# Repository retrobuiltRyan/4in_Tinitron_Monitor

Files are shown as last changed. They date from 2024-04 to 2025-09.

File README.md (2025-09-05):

# 4in_Tinitron_Monitor
4in 800x480 LCD Monitor that looks like a Sony Trinitron Wega.<br>
There are two different "TV" assemblies in this repo. <br>
a) TV shaped enclosure for a 4inch LCD <br>
b) TV shaped enclosure for a 4inch LCD + Raspberry Pi 3<br>
frame for commerical

https://www.youtube.com/watch?v=1_5VtVP_qF4
P1090145

mechanical overview

SIGNIFICANTLY IMPORTANT: This screen has a native portrait layout. Your HDMI source must support rotation. Otherwise this device will be useless.
If using a Pi, these settings [highlighted] will work.
Raspberry Pi 480x800 config settings

Parts and Links:
P1090100

### Parts List

| Item | Description | Qty | Cost | Line Total | Vendor | Link |
|---|---|-----|---|---|---|---|
| 1 | 4 Inch HD HDMI USB LCD Touch Screen 4" Display Module 800×480 TFT | 1 | $22.78 | $22.78 | AliExpress | [Link](https://www.aliexpress.us/item/3256803352252987.html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) |
| 2 | HDMI M-to-F 90 degree Ribbon Extension | 1 | $5.41  | $5.41 | AliExpress | [Link](https://www.aliexpress.us/item/3256802099720174.html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) |
| 3 | USB-C Panel Mount Breakout | 1 | $0.50  | $0.50 | AliExpress | [Link](https://www.aliexpress.us/item/3256805810676482.html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) |
| 4 | 3D printed Case (84 grams) | 1 | $1.25  | $1.25 | n/a | |
| 5 | Push Button latching 12mm dia (on/off switch) | 1 | $0.75  | $0.75 | ebay? | |
| 6 | M3 Threaded Inserts | 8 | $0.15  | $1.20 | amazon? | |
| 7 | M3x16mm button head hex screw | 2 | $0.05  | $0.10 | amazon? | |
| 8 | M3x6mm button head hex screw | 6 | $0.05  | $0.30 | amazon? | |
| 9 | M2 x 8mm head hex screw | 5 | $0.05  | $0.25 | amazon? | |
| 10 | M2 nuts | 2 | $0.02  | $0.04 | amazon? | |

**Total: $32.58**

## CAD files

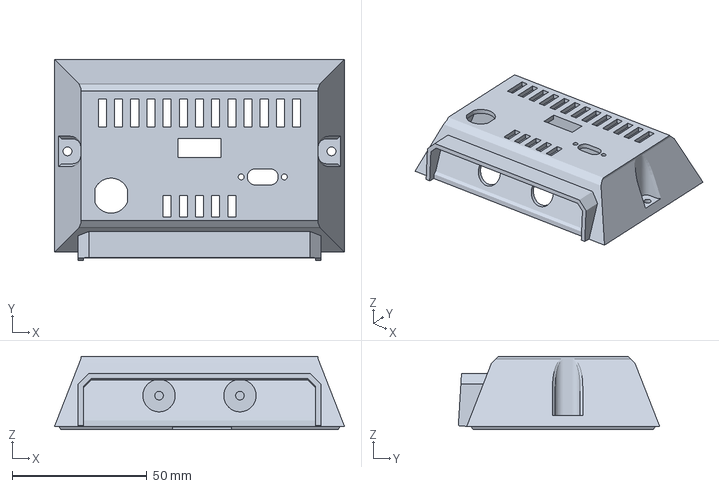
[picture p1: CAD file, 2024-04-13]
Tinitron Shell Body full base 1.1.3MF
107.5 x 74.7 x 27.2 mm

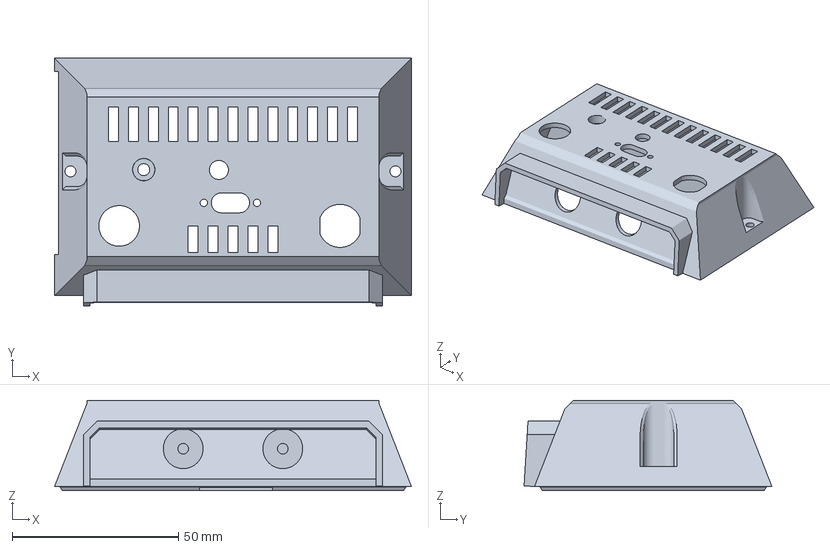
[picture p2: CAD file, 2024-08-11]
Tinitron Shell Rear+pi3.3MF
107.5 x 74.7 x 27.2 mm

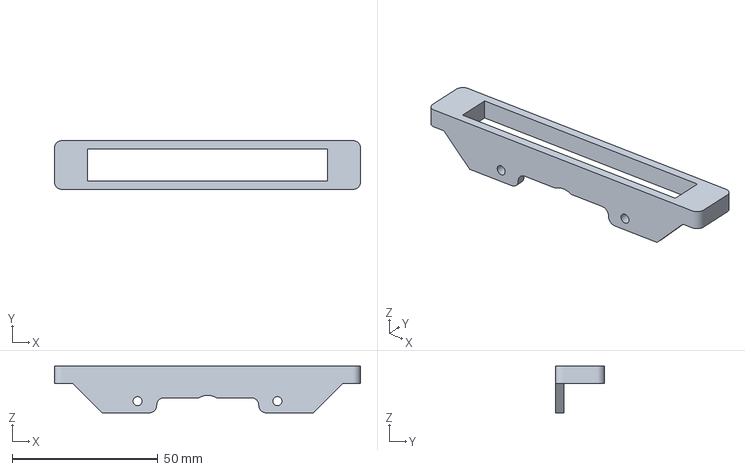
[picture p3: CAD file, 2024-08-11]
Volume LED Mount Bracket.3MF
105.0 x 16.8 x 16.0 mm

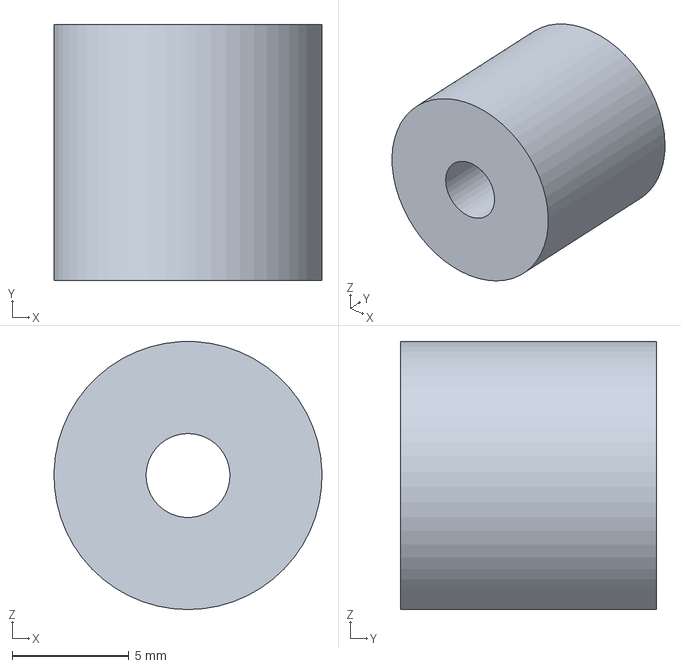
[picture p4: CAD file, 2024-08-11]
locator post.3MF
11.5 x 11.0 x 11.5 mm

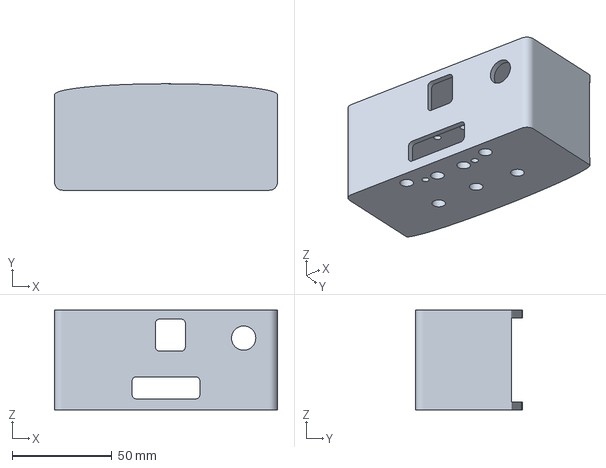
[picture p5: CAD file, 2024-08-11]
TV Stand.3MF
112.0 x 53.5 x 50.0 mm

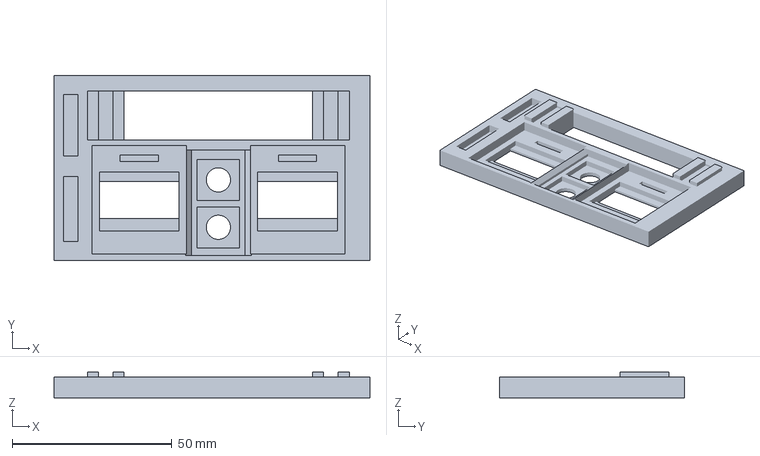
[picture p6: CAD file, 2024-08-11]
Audio Visualizer Insert.3MF
99.0 x 58.0 x 8.00 mm

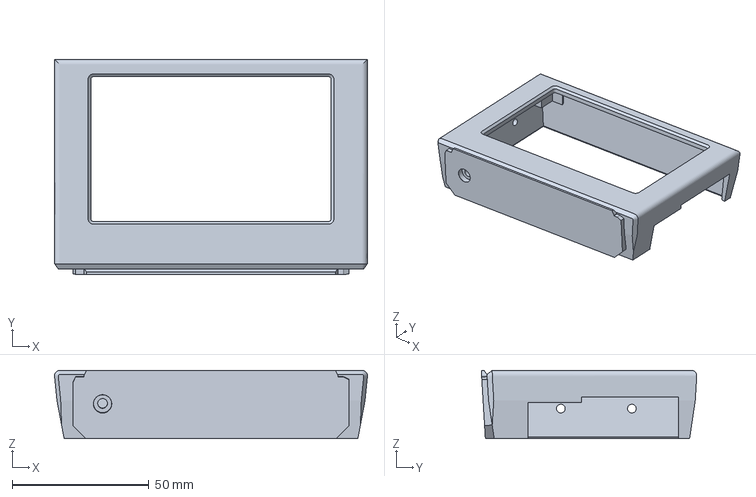
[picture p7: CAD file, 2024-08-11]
Tinitron Shell Front+pi3.3MF
114.6 x 78.9 x 25.0 mm

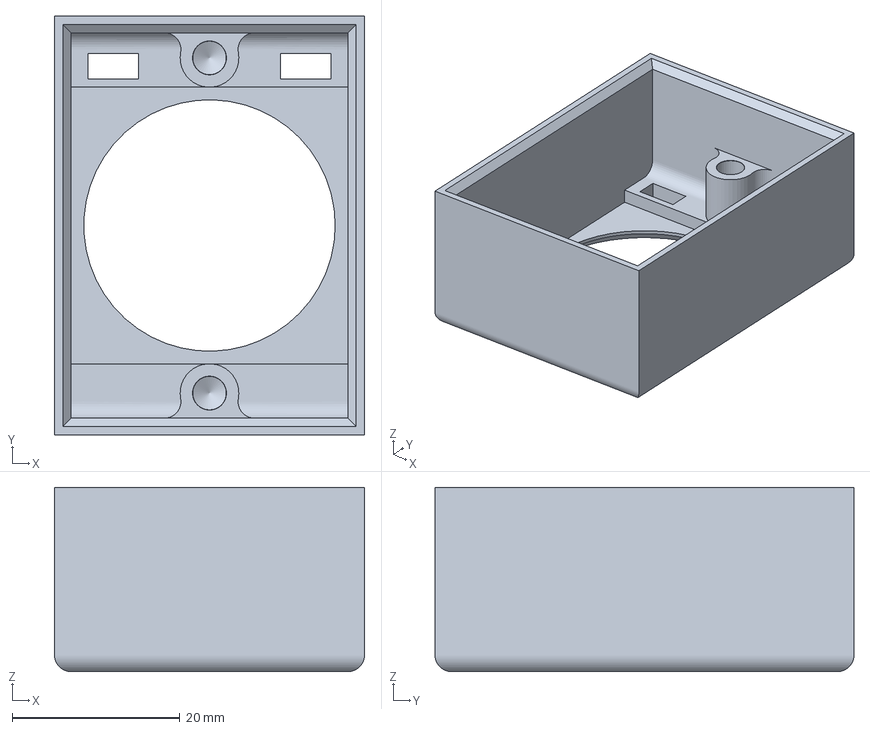
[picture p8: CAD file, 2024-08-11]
Speaker Box Front1.3MF
37.0 x 50.0 x 22.0 mm

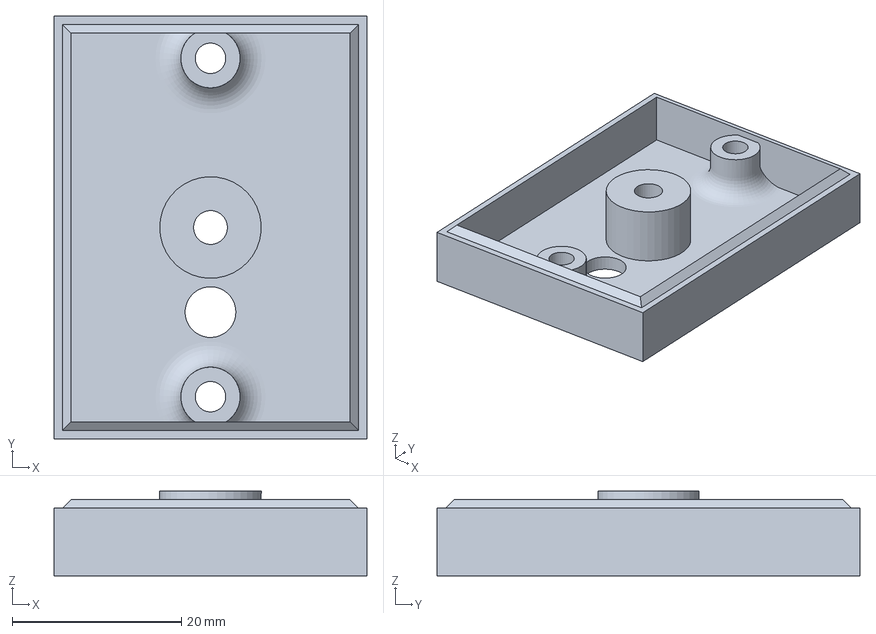
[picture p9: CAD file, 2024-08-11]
Speaker Box Back1.3MF
37.0 x 50.0 x 10.0 mm

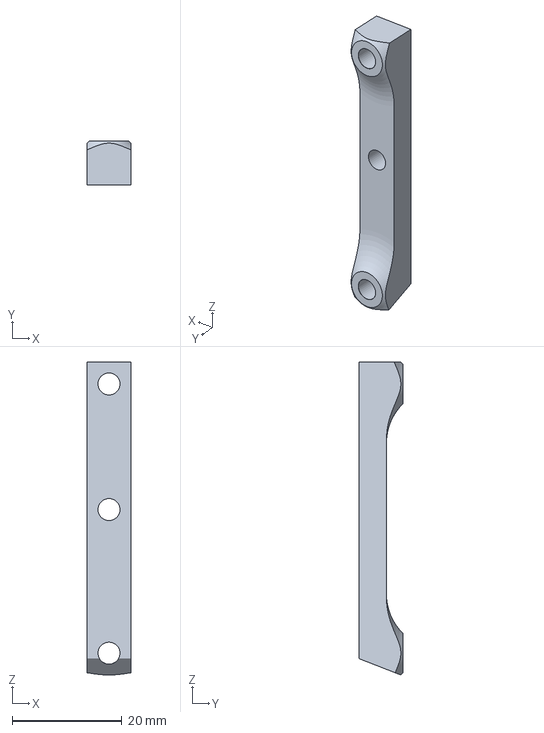
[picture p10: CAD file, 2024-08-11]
brace rear +pi3.3MF
8.00 x 8.00 x 57.0 mm

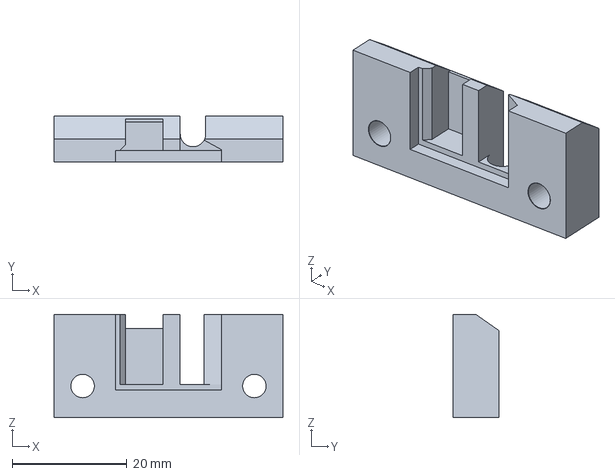
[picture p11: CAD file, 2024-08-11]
TRS bracket.3MF
40.0 x 8.00 x 18.0 mm

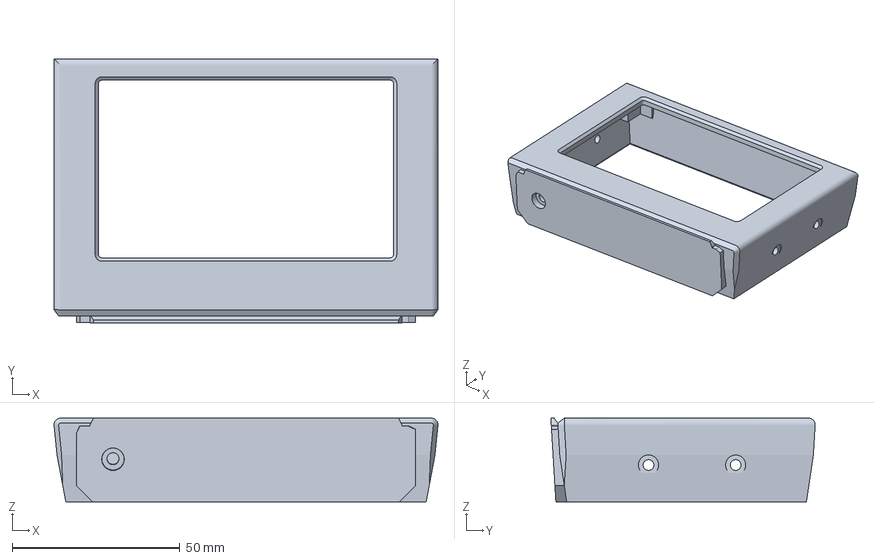
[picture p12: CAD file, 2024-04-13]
Tinitron Front.3MF
114.6 x 78.9 x 25.0 mm

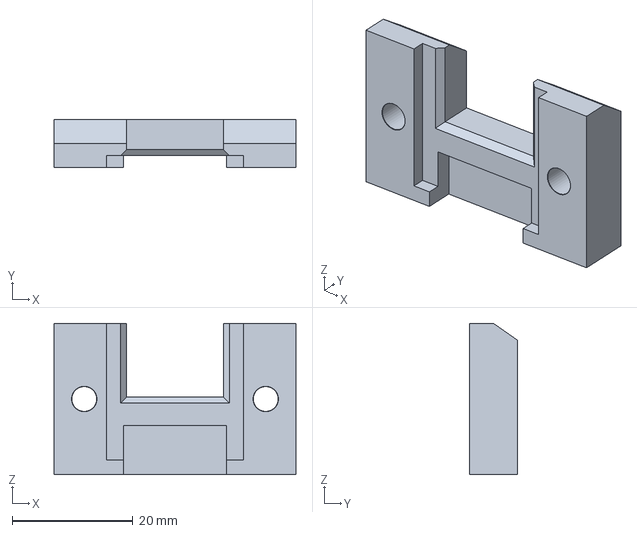
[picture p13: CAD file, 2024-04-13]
HDMI port Bracket.3MF
40.0 x 8.00 x 25.0 mm

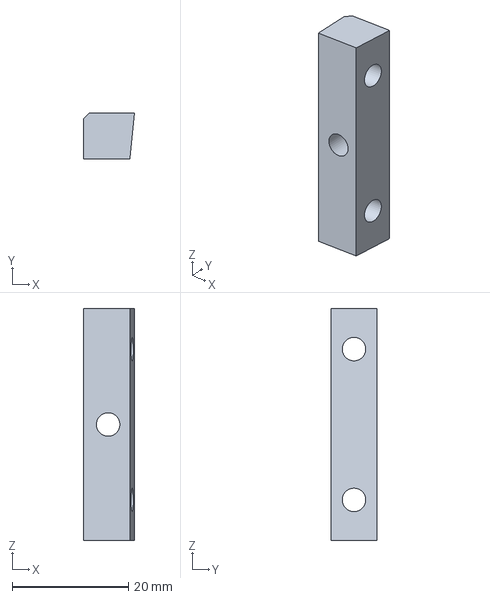
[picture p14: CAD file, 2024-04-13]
Tinitron Side Mount for Screen.3MF
8.80 x 8.00 x 40.0 mm

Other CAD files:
wedge.3MF

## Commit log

2024-04-13 3D Print Files
    Print 40% infill.
    [HDMI port Bracket.3MF, Tinitron Front.3MF, Tinitron Shell Body full base 1.1.3MF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]
2024-08-11 Pi Hi-Fi and Speakers extras
    Alternate Trinitron Enclosure to house a RPi3. TV stand and speakers.
    [Audio Visualizer Insert.3MF, Speaker Box Back1.3MF, Speaker Box Front1.3MF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]
